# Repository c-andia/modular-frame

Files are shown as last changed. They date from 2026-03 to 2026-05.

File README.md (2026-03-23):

# modular-frame

This is a repository compiling the files created for a photographic verification machine at Billet Precision Ltd., and aimed at documenting the important aspects of using and repairing the device.

The project involves a modular 3D-printable frame, which can be repurposed for use in other lightweight projects that need a weaker, cheaper alternative to aluminum extrusion. The electronics are built off of a Raspberry Pi 4.

If some part of the device has broken, check the BOM in the 'documentation' folder to find the replacement. If you would like to print a new frame or parts of a frame, check the 'frame-parts' folder for the 3D files.

If you would like to talk about the design, call me at (343) 462-8383 or e-mail candia.industrialdesign@gmail.com.

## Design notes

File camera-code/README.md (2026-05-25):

### The following is a reference for navigating the device's code structure.

**monitor_GPIO.py** Watches the input pins and describes the main feedback behaviour. It verifies that a viable USB storage device is connected, and then it then calls the take_photos program.
  Edit this file if: 
- The control behaviour must be changed.

**take_photos.py** configures the cameras, takes photos and sends them to the USB drive.
  Edit this file if:
- The USB must be changed or replaced.
- The cameras must be changed (not replaced).
- The camera configuration must be altered.

**bootErrorLog.txt** logs... boot errors...

**camera-launcher.sh** initiates monitor_GPIO at boot time.

*local files to be aware of:*

**crontab** is edited by typing 'crontab -e' into the terminal. It points the machine to where camera-launcher.sh is so it runs.

**bashrc** I'm not actually sure if it is used, but it might be a place to check if things aren't working. Type 'sudo nano ~/.bashrc' and look at the bottom line.

if a new USB is being attached, you need to set it up:

1. Find the UUID and type of the drive.
2. Create a mount point.
3. Mount the drive to the mount point (should be something like 'mount /mnt/mntname /dev/usbname/'
4. I think there is another step here that I forgot 😿 probably to do with cron or bashrc
5. Edit the variable 'USB_name' in take_photos.py to the new mountpoint name.

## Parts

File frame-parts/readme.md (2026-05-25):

### A brief description of each part:

**Innie + Outie:** The main parts that make up a length of the frame. Alternating these interlocking parts allows you to adjust the size.

**Extended Innie + Outie:** The brackets extended by 30mm. 

**L-joint:** A 90 degree connector.

**I-joint:** A 90 degree connector that meshes orthogonally with other joints to create a 3-dimensional joint.

**K- and C-joints:** Angular joints.

Outie parts have more than two holes. The inner holes with the hex couterbores allow a hex nut to be pushed through and external parts to be attached using an M6 bolt. The outer ones are for attaching innie parts.

#### Note: parts followed by 'l' and 'r' have no symmetry. This means that you must verify which direction of part is required or you will have considerable difficulty when it comes time to assemble.

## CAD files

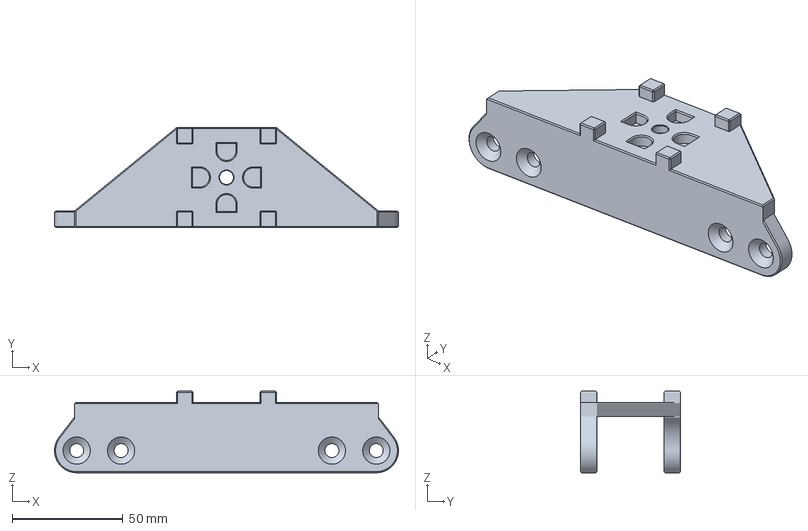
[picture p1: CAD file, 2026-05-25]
frame-parts/modular_mount_mk2.3mf
155.0 x 45.0 x 36.8 mm

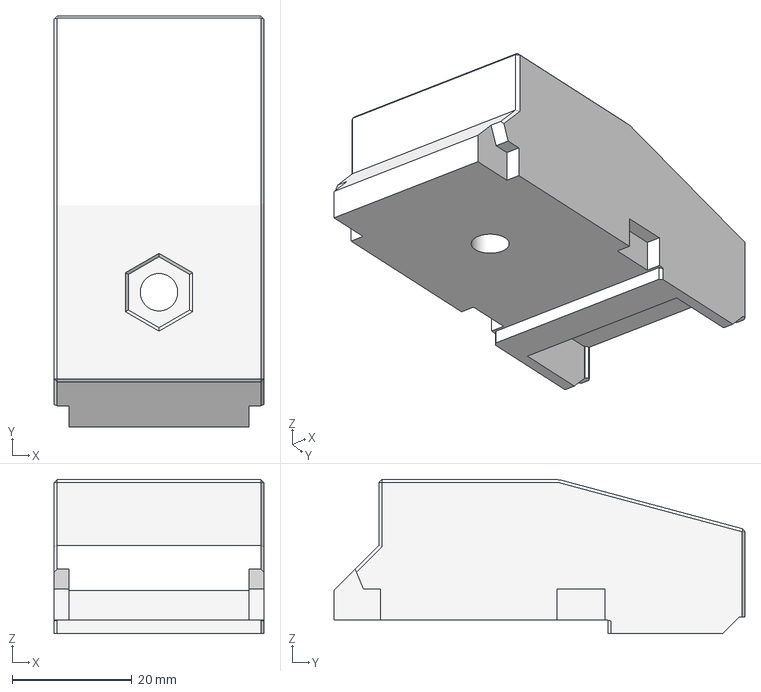
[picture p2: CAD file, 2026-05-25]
frame-parts/mk2_mount_top.3mf
35.0 x 68.6 x 25.7 mm

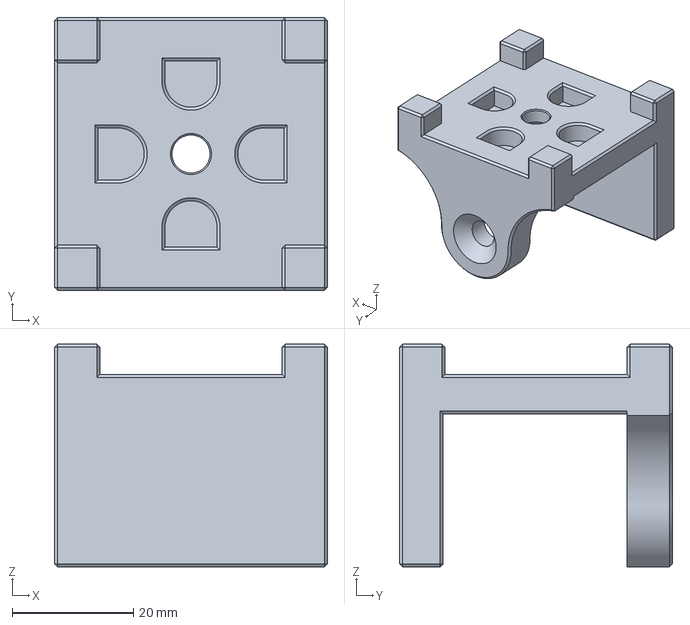
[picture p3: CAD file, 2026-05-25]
frame-parts/mini_mount_mk2.3mf
45.0 x 45.0 x 36.8 mm

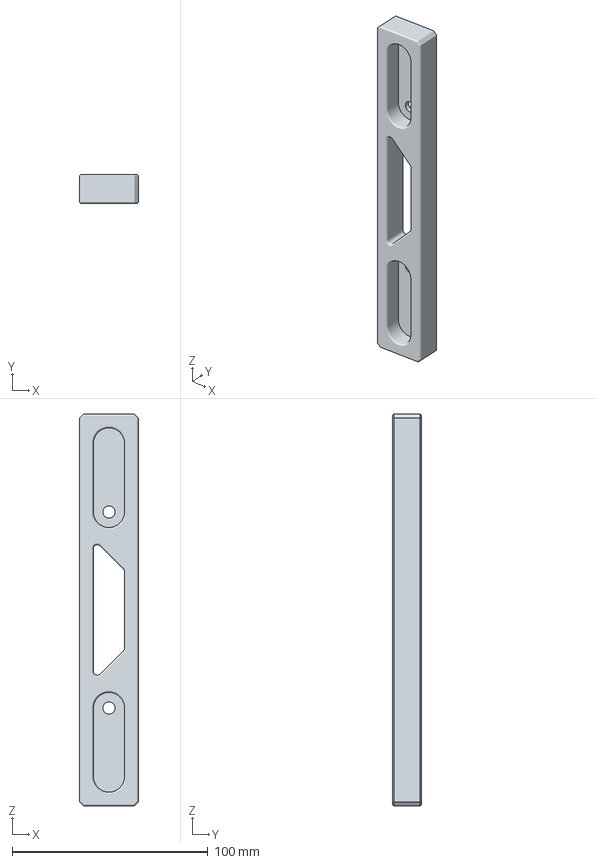
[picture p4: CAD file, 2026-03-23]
frame-parts/Innie_v5.3mf
30.0 x 15.0 x 200.0 mm

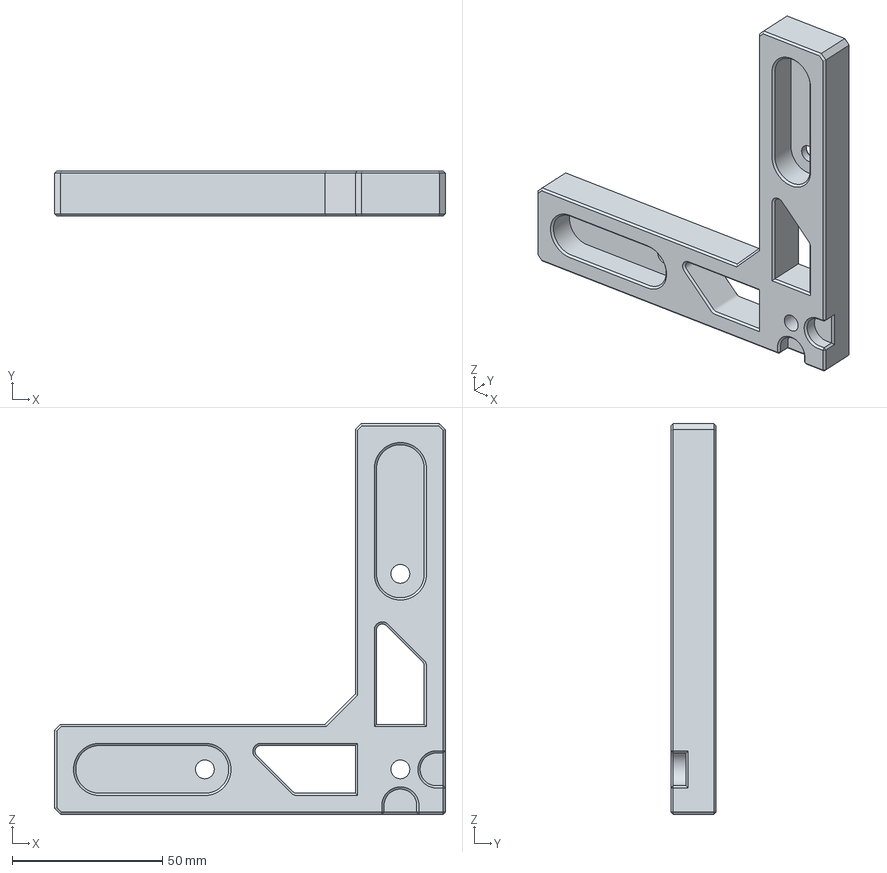
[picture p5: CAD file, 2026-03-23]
frame-parts/Joint_L_v5.3mf
130.0 x 15.0 x 130.0 mm

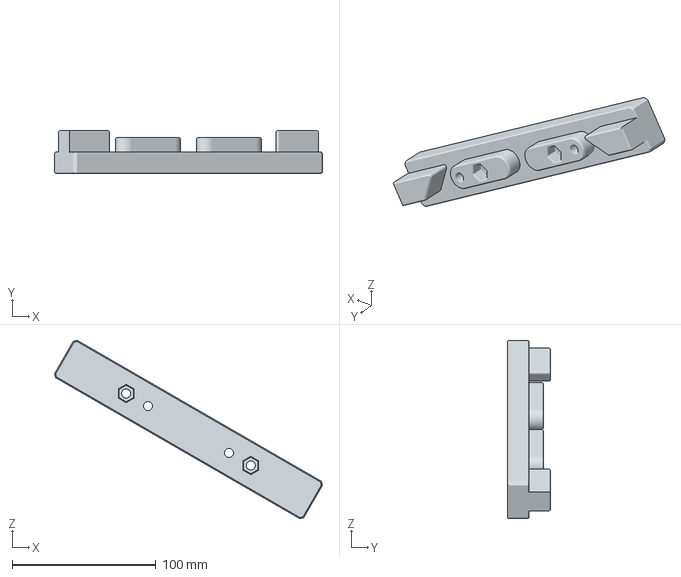
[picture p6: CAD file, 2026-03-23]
frame-parts/Outie_v5.3mf
186.2 x 30.0 x 124.0 mm

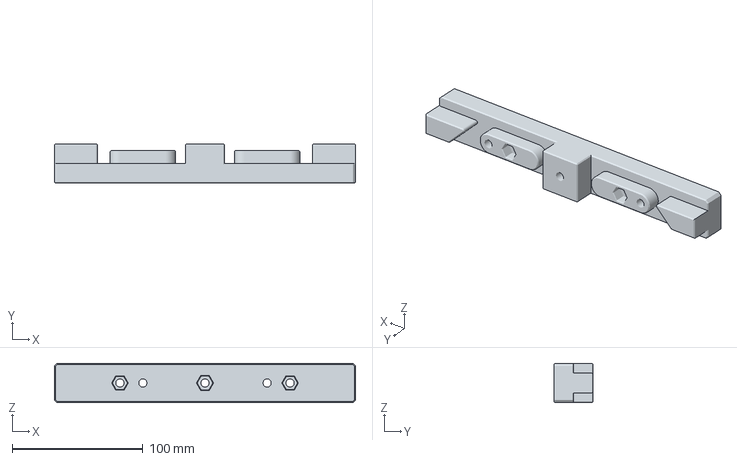
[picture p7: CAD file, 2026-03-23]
frame-parts/extended_outie_v5.3mf
230.0 x 30.0 x 30.0 mm

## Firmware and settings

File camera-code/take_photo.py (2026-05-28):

from datetime import datetime
import time
from picamera2 import Picamera2
from libcamera import controls, Transform
import pathlib

USB_name = '/mnt/Lexar'

def get_time():

        now = datetime.now()
        return now.strftime("%b. %-d, %Y, %-I.%M.%S %p")

def process_timer(stage):
        if stage == 'stop':
                print (f'time elapsed: {time.time()-start} seconds.')

                with open ("timelog.txt", "w") as i:
                        i.write (f'time elapsed: {time.time()-start} seconds.')

def capture():

        try:

                # create folder

                ftime = get_time()

                folderName = f"{USB_name}/Photos/'{ftime}'"
                pathlib.Path.mkdir(folderName)

                # take photos

                cam0.start()

                cam0.set_controls({"AfMode":controls.AfModeEnum.Auto})
                cam0.set_controls({"AfRange":controls.AfRangeEnum.Macro})
                cam0.set_controls({"AfTrigger":controls.AfTriggerEnum.Start})
                time.sleep(0.7)
                cam0.capture_file(f"{folderName}/photo 1.png")
#                cam0.set_controls({"AfTrigger":controls.AfTriggerEnum.Cancel})
                cam0.close()

                cam1.start()

                cam1.set_controls({"AfMode":controls.AfModeEnum.Auto})
                cam1.set_controls({"AfRange":controls.AfRangeEnum.Macro})
                cam1.set_controls({"AfTrigger":controls.AfTriggerEnum.Start})
                time.sleep(0.7)
                cam1.capture_file(f"{folderName}/photo 2.png")
#                cam1.set_controls({"AfTrigger":controls.AfTriggerEnum.Cancel})
                cam1.close()

                cam2.start()

                cam2.set_controls({"AfMode":controls.AfModeEnum.Auto})
                cam2.set_controls({"AfRange":controls.AfRangeEnum.Macro})
                cam2.set_controls({"AfTrigger":controls.AfTriggerEnum.Start})
                time.sleep(0.7)
                cam2.capture_file(f"{folderName}/photo 3.png")
#                cam2.set_controls({"AfTrigger":controls.AfTriggerEnum.Cancel})
                cam2.close()

                cam3.start()

                cam3.set_controls({"AfMode":controls.AfModeEnum.Auto})
                cam3.set_controls({"AfRange":controls.AfRangeEnum.Macro})
                cam3.set_controls({"AfTrigger":controls.AfTriggerEnum.Start})
                time.sleep(0.7)
                cam3.capture_file(f"{folderName}/photo 4.png")
#                cam3.set_controls({"AfTrigger":controls.AfTriggerEnum.Cancel})
                cam3.close()

        except FileExistsError:
                print("\nPlease wait before taking another photo.\n")

if __name__ == "__main__":


        cam0 = Picamera2(0)
        cam1 = Picamera2(1)
        cam2 = Picamera2(2)
        cam3 = Picamera2(3)

        cam0.configure(cam0.create_still_configuration(transform=Transform(hflip=True, vflip=True)))
        cam1.configure(cam1.create_still_configuration(transform=Transform(hflip=True, vflip=True)))
        cam2.configure(cam2.create_still_configuration(transform=Transform(hflip=True, vflip=True)))
        cam3.configure(cam3.create_still_configuration(transform=Transform(hflip=True, vflip=True)))

        start = time.time()

        try:
                capture()

        finally:
                process_timer('stop')

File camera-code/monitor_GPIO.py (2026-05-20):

import time
import os
from datetime import datetime
import take_photo
import RPi.GPIO as GPIO
from picamera2 import Picamera2
import pathlib
import subprocess
import pyudev

folder_name="/mnt/Lexar/Photos"

GPIO.setmode(GPIO.BOARD)
greenPin=36
yellowPin=38
inPin=40

GPIO.setup(inPin, GPIO.IN, pull_up_down=GPIO.PUD_UP)
GPIO.setup(yellowPin, GPIO.OUT)
GPIO.setup(greenPin, GPIO.OUT)

wait_for_release = False
MONITORING = True

def check_usb():

    context = pyudev.Context()

    for device in context.list_devices(subsystem='block', DEVTYPE='partition'):
        if device.get('ID_BUS') == 'usb':
            return True
    return False

def flash_led(colPin, flashDuration):

	GPIO.output(greenPin, 0)
	GPIO.output(yellowPin, 0)

	for i in range(flashDuration):

		GPIO.output(colPin, 1)
		time.sleep(0.2)
		GPIO.output(colPin, 0)
		time.sleep(0.2)

try:
	GPIO.output(greenPin, 0)
	GPIO.output(yellowPin, 0)

	time.sleep(2)

	flash_led(greenPin, 2)

	while MONITORING == True:

		button_state = GPIO.input(inPin)

		if button_state == GPIO.LOW:

			wait_for_release = True
			GPIO.output(greenPin, 1)

		if wait_for_release == False and button_state == GPIO.HIGH:
			pass

		if wait_for_release == True and button_state == GPIO.HIGH:

			GPIO.output(greenPin, 0)
			GPIO.output(yellowPin, 1)
			usb_is_there = check_usb()

			if usb_is_there == 0:

				flash_led(yellowPin, 3)
				print("USB is not connected")

			else:
				subprocess.run(['sudo', 'python3', 'take_photo.py'])
				GPIO.output(yellowPin, 0)
				flash_led(greenPin, 4)
				GPIO.output(greenPin, 1)
				time.sleep(0.4)

			GPIO.output(yellowPin, 0)
			GPIO.output(greenPin, 0)

			wait_for_release = False

except KeyboardInterrupt:
	print("interrupted")

finally:
	for i in range(2):
		flash_led(greenPin, 1)
		flash_led(yellowPin, 1)

	GPIO.cleanup()

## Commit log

2026-05-20 Added more feedback, fixed bash scripts
    [monitor_GPIO.py]
2026-05-21 Update take_photo.py
    added AfRange control 🙏
2026-05-22 code fixed, testfile added
    [take_photo.py]
2026-05-25 Add files via upload
    Added modular mounts.
    mini mount mk2: small profile mount, which can attach to one side of the frame.
    modular mount mk2: larger profile mount which can attach to both sides of the frame. In one of its orientations, this mount can be attached with three screws at once, for maximum security: it also bridges between two joints, creating a reinforcement at their connection.
    top mount: used to mount the camera directly to the frame.
    [mini_mount_mk2.3mf, mk2_mount_top.3mf, modular_mount_mk2.3mf]
